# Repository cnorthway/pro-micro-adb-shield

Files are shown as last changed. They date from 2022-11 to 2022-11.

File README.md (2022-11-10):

# Pro Micro ADB "Shield"

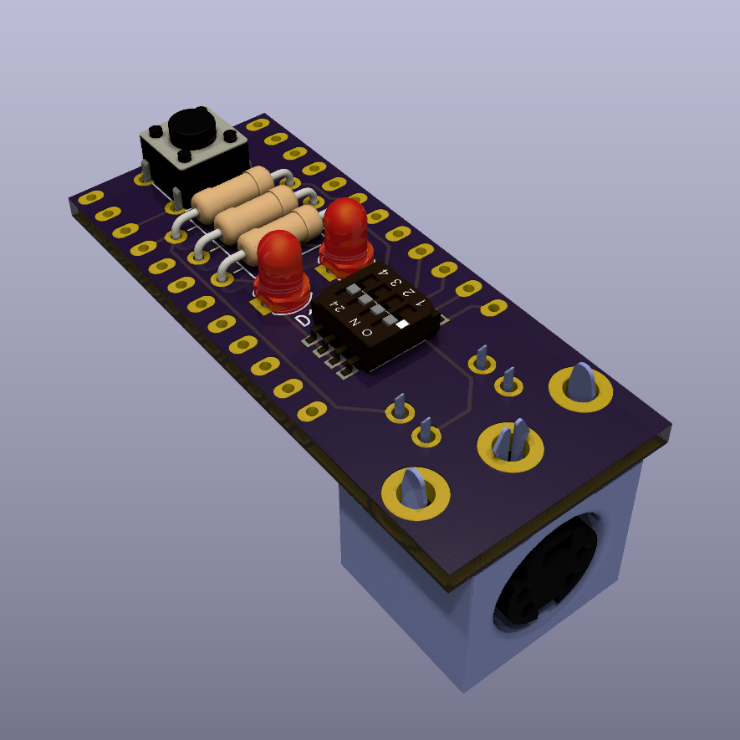
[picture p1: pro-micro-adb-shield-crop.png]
3D render of PCB


A simple PCB designed to add an Apple Desktop Bus (ADB) port to an Arduino
Pro Micro board to create a USB-ADB converter with a few extra features.
Uses mostly through-hole components.

Software is based on TMK's existing USB-ADB converter, see the
[firmware repo][fwrepo] for more details.

## Features
- DIP switch for on-the-fly modification of keymaps
- LEDs for Caps and Num Lock status
- Uses through hole components for ease of assembly (+ aesthetics, really)
- Based on a Pro Micro to avoid reinventing the atmega32 wheel, and to give
  some modicum of insurance against chip shortage insanity

## BOM / Assembly

Parts List:

| Ref. | Description / Value |
| --- | --- |
| U1 | Arduino Pro Micro (5V) |
| J1 | 4 pin DIN socket, Kycon `KMDGX-4S-BS` or compatible |
| SW1 | Through-hole mini pushbutton, TE Connectivity `1825910-7` or compatible |
| SW2 | 4 position surface mount DIP switch, CTS Electronics `214-LPST` or compatible |
| R1, R2 | 1/4 W through hole resistor, value dependent on LED |
| R3 | 1/4 W through hole resistor, 470 ohm (pullup for ADB, see [here][tmkwiki]) |
| D1, D2 | 3mm through-hole LEDs |

[tmkwiki]: https://github.com/tmk/tmk_keyboard/wiki/Apple-Desktop-Bus#pull-up-resistor

Steps:

1. Solder SMD DIP switch to shield
2. Solder all through hole parts to shield, trim legs
3. Short jumper on Pro Micro to set 5V logic levels
4. Solder headers to Pro Micro
5. Test LEDs, etc -- you won't be able to remove them later!
6. Stack boards together and solder headers to shield
7. Trim excess header length from shield side
8. Flash Pro Micro with [firmware][fwrepo]; optionally customize keymaps

[fwrepo]: https://github.com/cnorthway/tmk_keyboard/tree/cnorthway/adapter

## Note About 3D Models

I am not redistributing the third party 3D models, so if you want the full 3D
rendered experience: find them yourself, place them in a folder and add that
folder to Kicad with `Preferences->Configure Paths...` as `CUSTOM3D`.

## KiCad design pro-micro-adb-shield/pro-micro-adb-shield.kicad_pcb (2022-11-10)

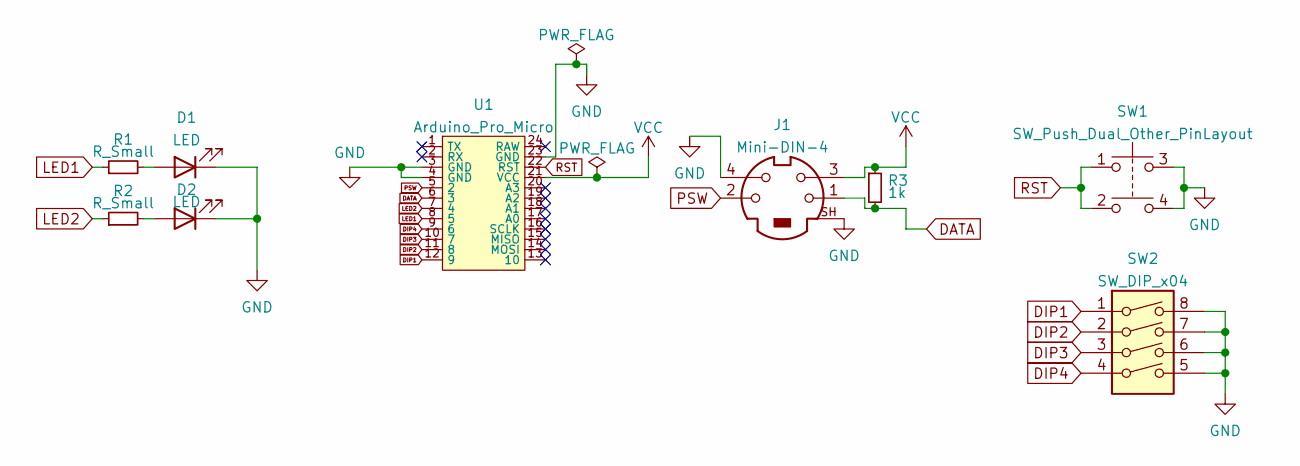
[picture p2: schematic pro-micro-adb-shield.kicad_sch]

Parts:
D1, D2: LED; LED_D3.0mm
J1: Mini-DIN-4; Mini-DIN-4_KMDGX-4S-BS
R1, R2: R_Small; R_Axial_DIN0207_L6.3mm_D2.5mm_P10.16mm_Horizontal
R3: 1k; R_Axial_DIN0207_L6.3mm_D2.5mm_P10.16mm_Horizontal
SW1: SW_Push_Dual_Other_PinLayout; SW_TH_Tactile_Omron_B3F-10xx
SW2: SW_DIP_x04; 218-4LPST
U1: Arduino_Pro_Micro

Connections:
DATA: J1.1, R3.2, U1.6 (3)
DIP1: SW2.1, U1.12 (9)
DIP2: SW2.2, U1.11 (8)
DIP3: SW2.3, U1.10 (7)
DIP4: SW2.4, U1.9 (6)
GND: D1.1 (K), D2.1 (K), J1.4, J1.SH, SW1.3, SW1.4, SW2.5, SW2.6, SW2.7, SW2.8, U1.3 (GND), U1.4 (GND), U1.23 (GND)
LED1: R1.1, U1.8 (5)
LED2: R2.1, U1.7 (4)
unnamed: D1.2 (A), R1.2
unnamed: D2.2 (A), R2.2
PSW: J1.2, U1.5 (2)
RST: SW1.1, SW1.2, U1.22 (RST)
VCC: J1.3, R3.1, U1.21 (VCC)

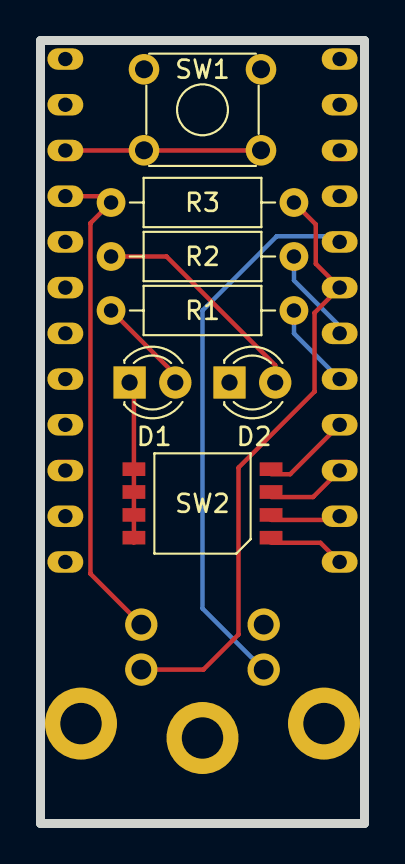
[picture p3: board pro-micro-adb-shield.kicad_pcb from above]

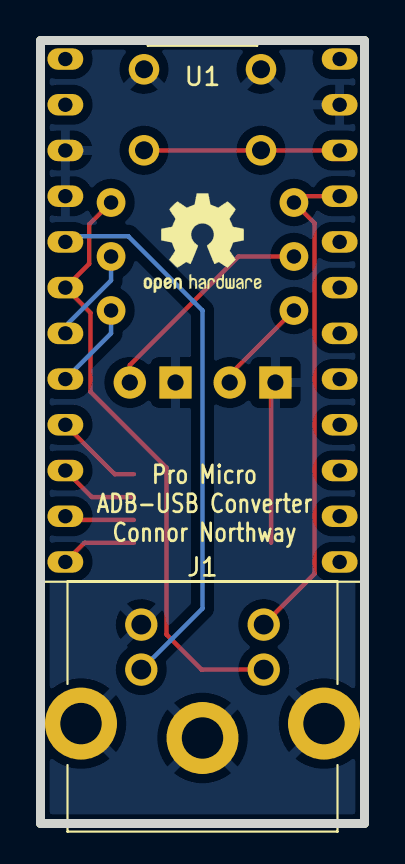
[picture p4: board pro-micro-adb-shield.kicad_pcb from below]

Board: 2 copper layers, 18.0 x 43.5 mm, 9 parts (2 on the bottom side), 13 nets.

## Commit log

2021-07-28 Create adapter PCB
    [pro-micro-adb-shield.kicad_pcb, pro-micro-adb-shield.kicad_sch]
2021-07-28 Add 3D model for switch, setup OSHPark constraints
    [pro-micro-adb-shield.kicad_pcb]
2021-07-28 Modify edge cut, add silkscreen
    [pro-micro-adb-shield.kicad_pcb]
2022-11-07 Fix shorted RST/GND through button
    why does this sort of thing always show up the day after you
    send the gerbers in to be manufactured >:(
    [pro-micro-adb-shield.kicad_pcb, pro-micro-adb-shield.kicad_sch]
2022-11-07 Use env var for 3d models, flip net names for DIP
    [pro-micro-adb-shield.kicad_pcb, pro-micro-adb-shield.kicad_sch]
2022-11-07 Use built-in switch 3D model, make LED 3D flush
    [pro-micro-adb-shield.kicad_pcb]
2022-11-07 Add README
    includes assembly instructions and parts list
2022-11-10 DRC check
    remove one sneaky stub trace
    refill zones
    ignore screaming about silkscreen
    [pro-micro-adb-shield.kicad_pcb]
2022-11-10 Change pullup value in README
    just tried daisy chaining two devices for the first time using 4.7k,
    didn't work. swapped for 470 ohm, works great in all configurations
    probably more leeway, but 470 ohm seems to be reliable so i'll
    recommend that.
